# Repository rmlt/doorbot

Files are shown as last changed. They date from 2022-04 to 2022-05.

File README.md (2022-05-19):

# doorbot
Software for our DoorBot

The DoorBot is a device connected to our doorphone that opens the office doors as required.

This software runs on a Raspberry Pi connected to a circuit board that allows it to:
* get input from the doorphone LED and the doorbell button
* simulate pressing a button on the doorphone
* move a servo attached to the door handle
* play sounds

TODO:
* black, isort
* split into modules
* logging instead of printing
* add some photos

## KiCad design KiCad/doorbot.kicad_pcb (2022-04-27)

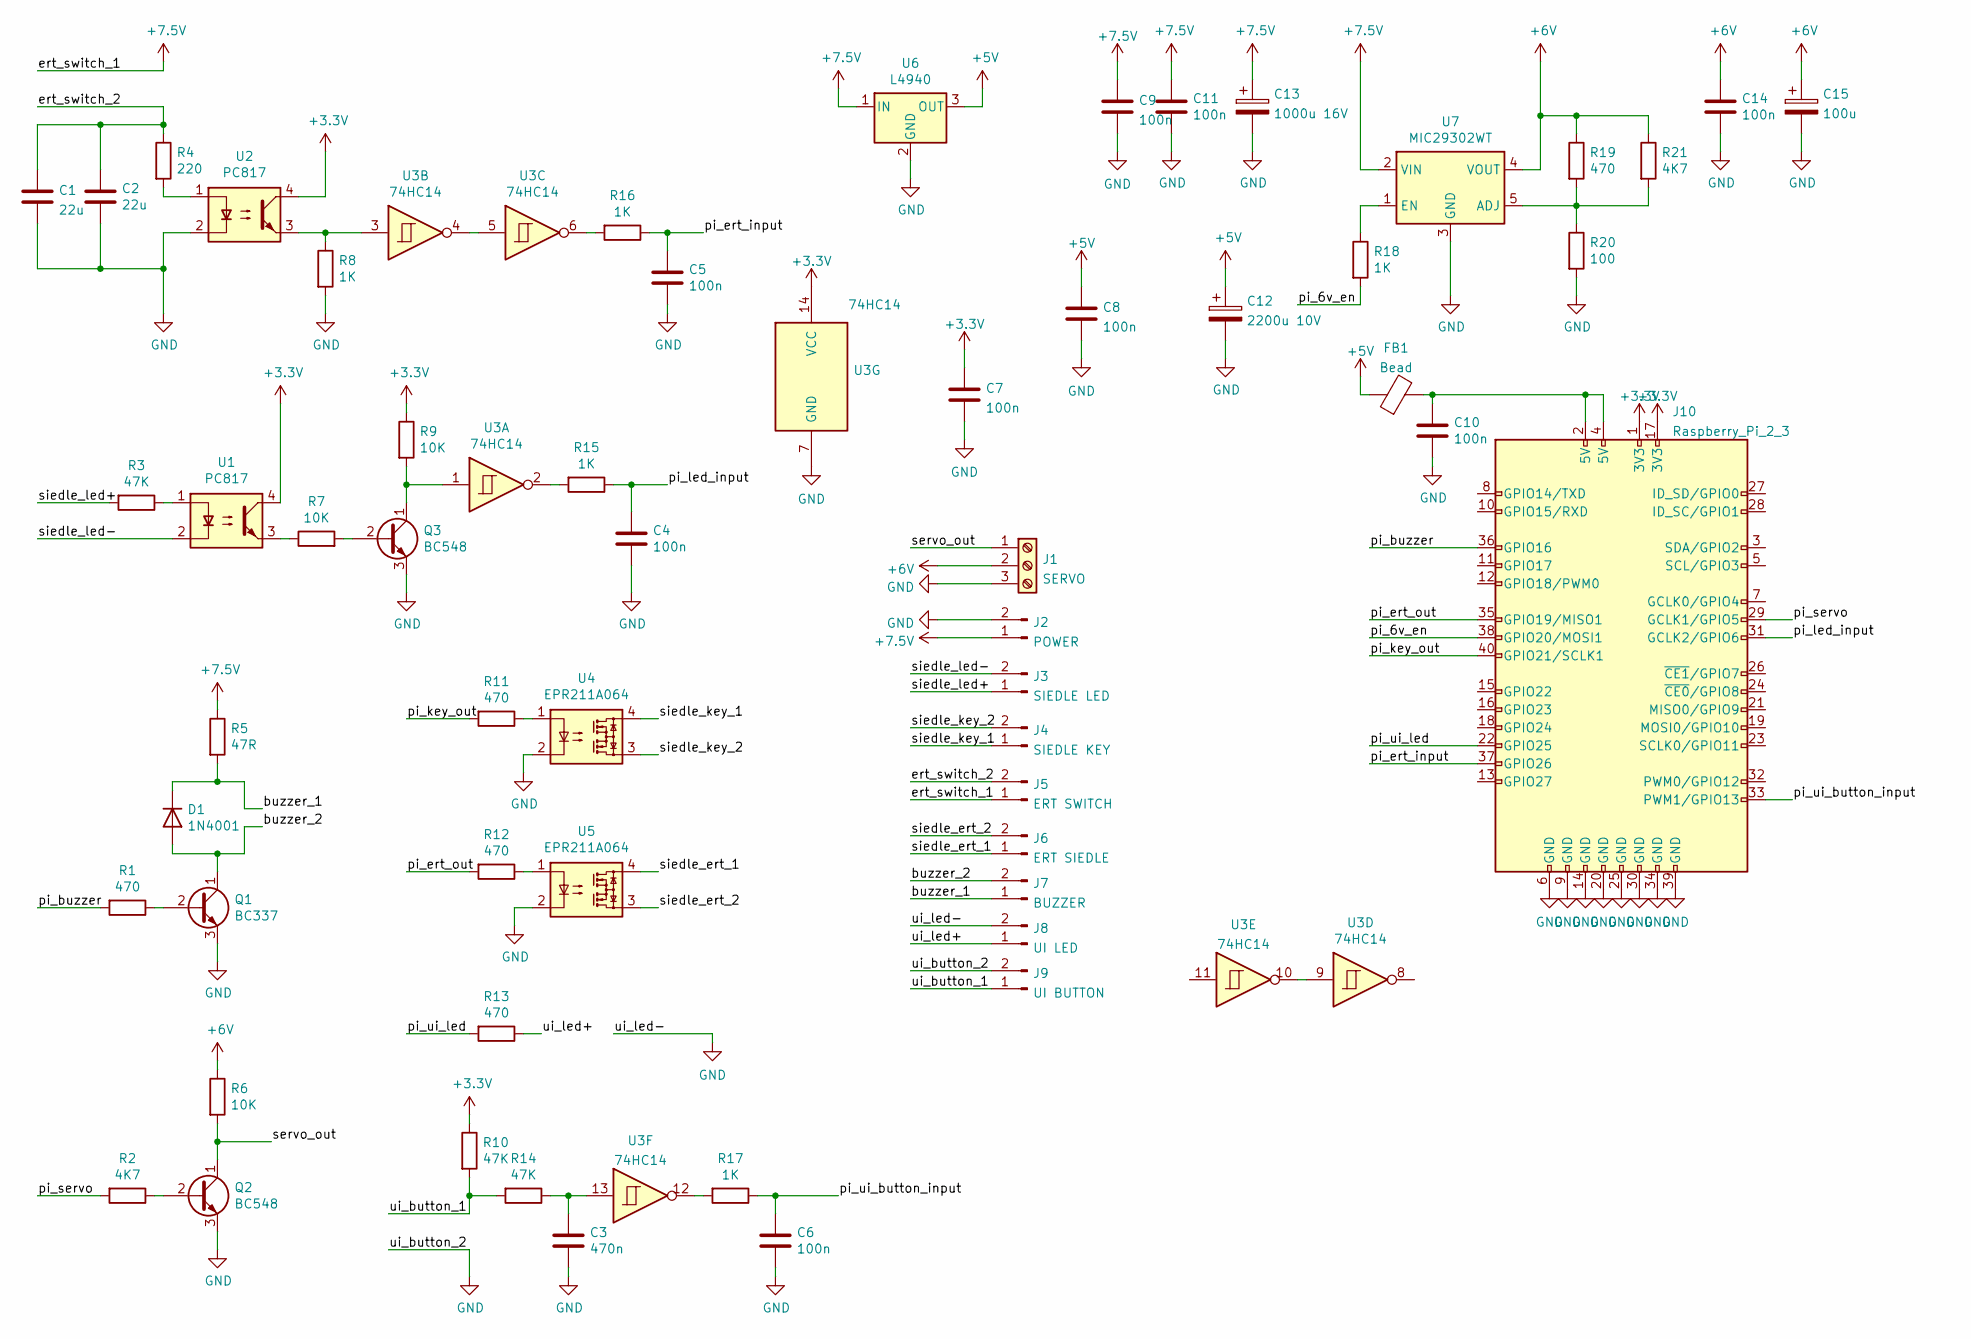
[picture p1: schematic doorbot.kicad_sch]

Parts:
C1, C2: 22u; C_1210_3225Metric
C3: 470n; C_Disc_D5.0mm_W2.5mm_P2.50mm
C4, C5, C6, C8, C9, C10, C11, C14: 100n; C_Disc_D5.0mm_W2.5mm_P2.50mm
C7: 100n; C_Disc_D7.5mm_W5.0mm_P7.50mm
C12: 2200u 10V; CP_Radial_D12.5mm_P5.00mm
C13: 1000u 16V; CP_Radial_D12.5mm_P5.00mm
C15: 100u; CP_Radial_D10.0mm_P2.50mm
D1: 1N4001; D_DO-41_SOD81_P2.54mm_Vertical_AnodeUp
FB1: Bead; R_Axial_DIN0207_L6.3mm_D2.5mm_P10.16mm_Horizontal
J1: SERVO; TerminalBlock_bornier-3_P5.08mm
J2: POWER; PinHeader_1x02_P2.54mm_Vertical
J3: SIEDLE LED; PinHeader_1x02_P2.54mm_Vertical
J4: SIEDLE KEY; PinHeader_1x02_P2.54mm_Vertical
J5: ERT SWITCH; PinHeader_1x02_P2.54mm_Vertical
J6: ERT SIEDLE; PinHeader_1x02_P2.54mm_Vertical
J7: BUZZER; PinHeader_1x02_P2.54mm_Vertical
J8: UI LED; PinHeader_1x02_P2.54mm_Vertical
J9: UI BUTTON; PinHeader_1x02_P2.54mm_Vertical
J10: Raspberry_Pi_2_3; PinSocket_2x20_P2.54mm_Vertical
Q1: BC337; TO-92_Inline_Wide
Q2, Q3: BC548; TO-92_Inline_Wide
R1, R19: 470; R_Axial_DIN0207_L6.3mm_D2.5mm_P2.54mm_Vertical
R2, R21: 4K7; R_Axial_DIN0207_L6.3mm_D2.5mm_P2.54mm_Vertical
R3, R14: 47K; R_Axial_DIN0207_L6.3mm_D2.5mm_P5.08mm_Vertical
R4: 220; R_Axial_DIN0207_L6.3mm_D2.5mm_P2.54mm_Vertical
R5: 47R; R_Axial_DIN0207_L6.3mm_D2.5mm_P5.08mm_Vertical
R6: 10K; R_Axial_DIN0207_L6.3mm_D2.5mm_P2.54mm_Vertical
R7, R9: 10K; R_Axial_DIN0207_L6.3mm_D2.5mm_P10.16mm_Horizontal
R8: 1K; R_Axial_DIN0207_L6.3mm_D2.5mm_P10.16mm_Horizontal
R10: 47K; R_Axial_DIN0309_L9.0mm_D3.2mm_P12.70mm_Horizontal
R11, R13: 470; R_Axial_DIN0207_L6.3mm_D2.5mm_P5.08mm_Vertical
R12: 470; R_Axial_DIN0207_L6.3mm_D2.5mm_P10.16mm_Horizontal
R15: 1K; R_Axial_DIN0309_L9.0mm_D3.2mm_P12.70mm_Horizontal
R16: 1K; R_Axial_DIN0207_L6.3mm_D2.5mm_P15.24mm_Horizontal
R17: 1K; R_Axial_DIN0207_L6.3mm_D2.5mm_P2.54mm_Vertical
R18: 1K; R_Axial_DIN0207_L6.3mm_D2.5mm_P5.08mm_Vertical
R20: 100; R_Axial_DIN0207_L6.3mm_D2.5mm_P5.08mm_Vertical
U1, U2: PC817; DIP-4_W7.62mm
U3: 74HC14; DIP-14_W7.62mm
U4, U5: EPR211A064; DIP-4_W7.62mm
U6: L4940; TO-220-3_Horizontal_TabDown
U7: MIC29302WT; R_Array_SIP5

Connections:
+3V3: C7.1, J10.1 (3V3), J10.17 (3V3), R9.1, R10.1, U1.4, U2.4, U3.14 (VCC)
+5V: C8.1, C12.1, FB1.1, U6.3 (OUT)
+6V: C14.1, C15.1, J1.2, R6.1, R19.1, R21.1, U7.4 (VOUT)
+7.5V: C9.1, C11.1, C13.1, J2.1, J5.1, R5.1, U6.1 (IN), U7.2 (VIN)
/buzzer_1: D1.1 (K), J7.1, R5.2
/buzzer_2: D1.2 (A), J7.2, Q1.1 (C)
/ert_switch_2: C1.1, C2.1, J5.2, R4.1
/pi_6v_en: J10.38 (GPIO20/MOSI1), R18.2
/pi_buzzer: J10.36 (GPIO16), R1.2
/pi_ert_input: C5.1, J10.37 (GPIO26), R16.1
/pi_ert_out: J10.35 (GPIO19/MISO1), R12.2
/pi_key_out: J10.40 (GPIO21/SCLK1), R11.2
/pi_led_input: C4.1, J10.31 (GCLK2/GPIO6), R15.1
/pi_servo: J10.29 (GCLK1/GPIO5), R2.2
/pi_ui_button_input: C6.1, J10.33 (PWM1/GPIO13), R17.1
/pi_ui_led: J10.22 (GPIO25), R13.2
/servo_out: J1.1, Q2.1 (C), R6.2
/siedle_ert_1: J6.1, U5.4
/siedle_ert_2: J6.2, U5.3
/siedle_key_1: J4.1, U4.4
/siedle_key_2: J4.2, U4.3
/siedle_led+: J3.1, R3.2
/siedle_led-: J3.2, U1.2
/ui_button_1: J9.1, R10.2, R14.2
/ui_led+: J8.1, R13.1
GND: C1.2, C2.2, C3.2, C4.2, C5.2, C6.2, C7.2, C8.2, C9.2, C10.2, C11.2, C12.2, C13.2, C14.2, C15.2, J1.3, J2.2, J8.2, J9.2, J10.6 (GND), J10.9 (GND), J10.14 (GND), J10.20 (GND), J10.25 (GND), J10.30 (GND), J10.34 (GND), J10.39 (GND), Q1.3 (E), Q2.3 (E), Q3.3 (E), R8.2, R20.2, U2.2, U3.7 (GND), U4.2, U5.2, U6.2 (GND), U7.3 (GND)
unnamed: C3.1, R14.1, U3.13
unnamed: C10.1, FB1.2, J10.2 (5V), J10.4 (5V)
unnamed: Q1.2 (B), R1.1
unnamed: Q2.2 (B), R2.1
unnamed: Q3.1 (C), R9.2, U3.1
unnamed: Q3.2 (B), R7.2
unnamed: R3.1, U1.1
unnamed: R4.2, U2.1
unnamed: R7.1, U1.3
unnamed: R8.1, U2.3, U3.3
unnamed: R11.1, U4.1
unnamed: R12.1, U5.1
unnamed: R15.2, U3.2
unnamed: R16.2, U3.6
unnamed: R17.2, U3.12
unnamed: R18.1, U7.1 (EN)
unnamed: R19.2, R20.1, R21.2, U7.5 (ADJ)
unnamed: U3.4, U3.5
unnamed: U3.9, U3.10

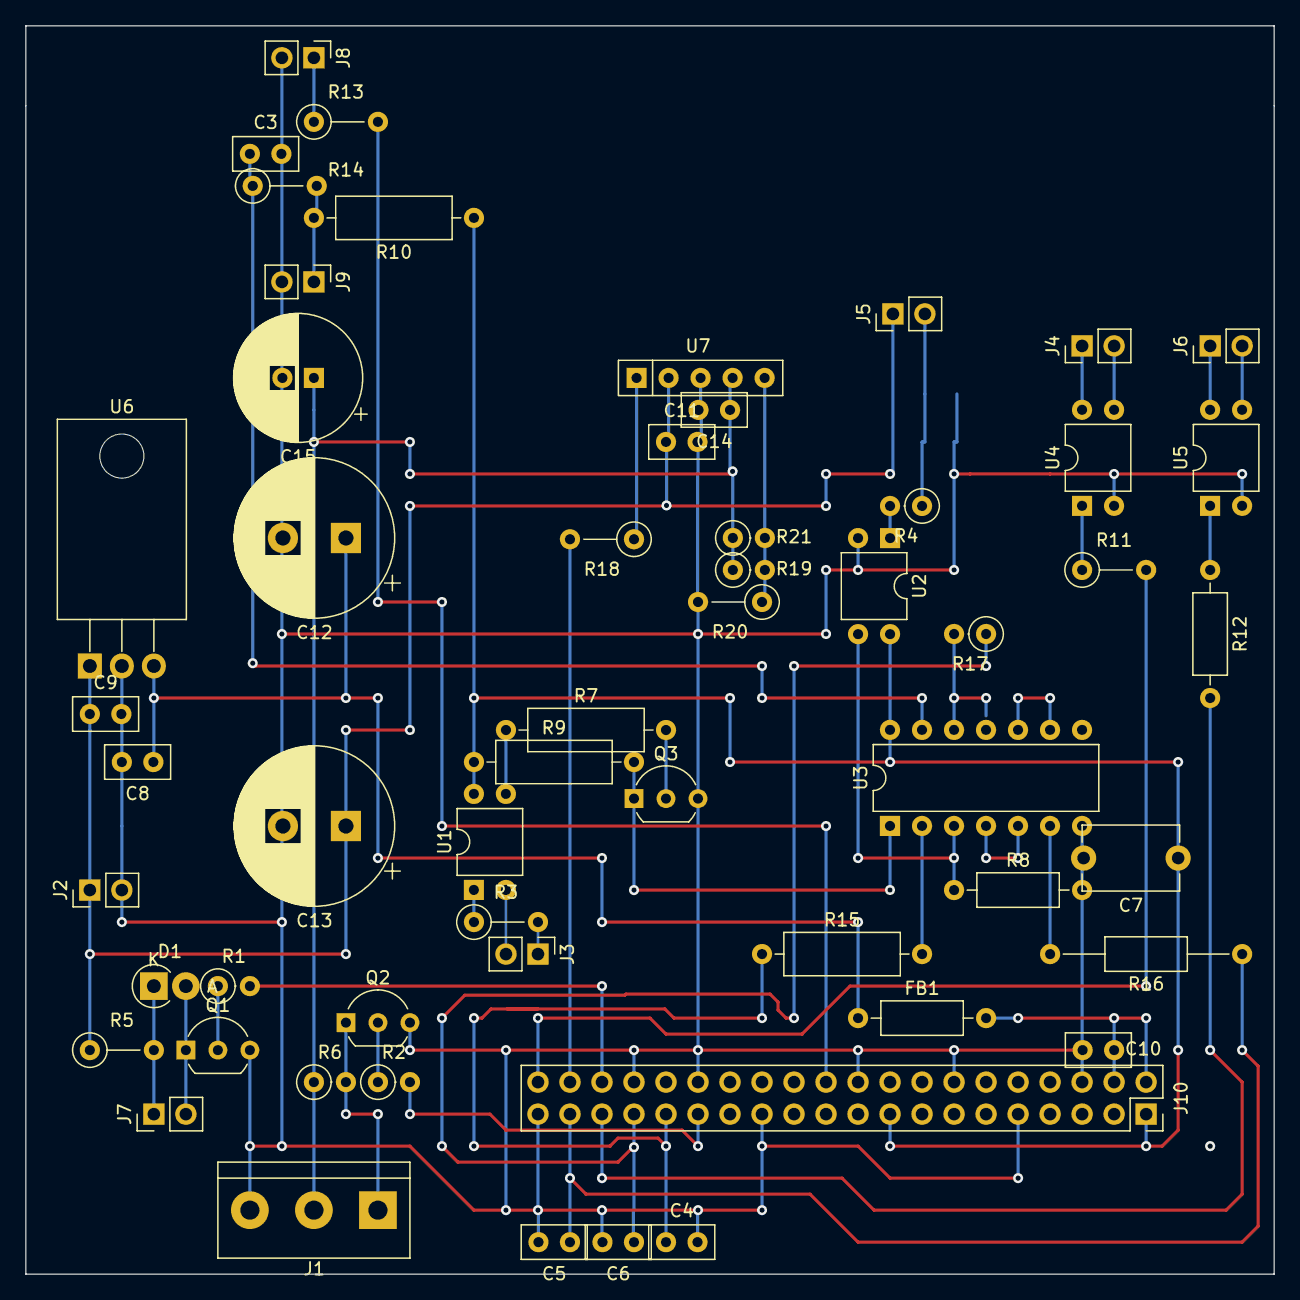
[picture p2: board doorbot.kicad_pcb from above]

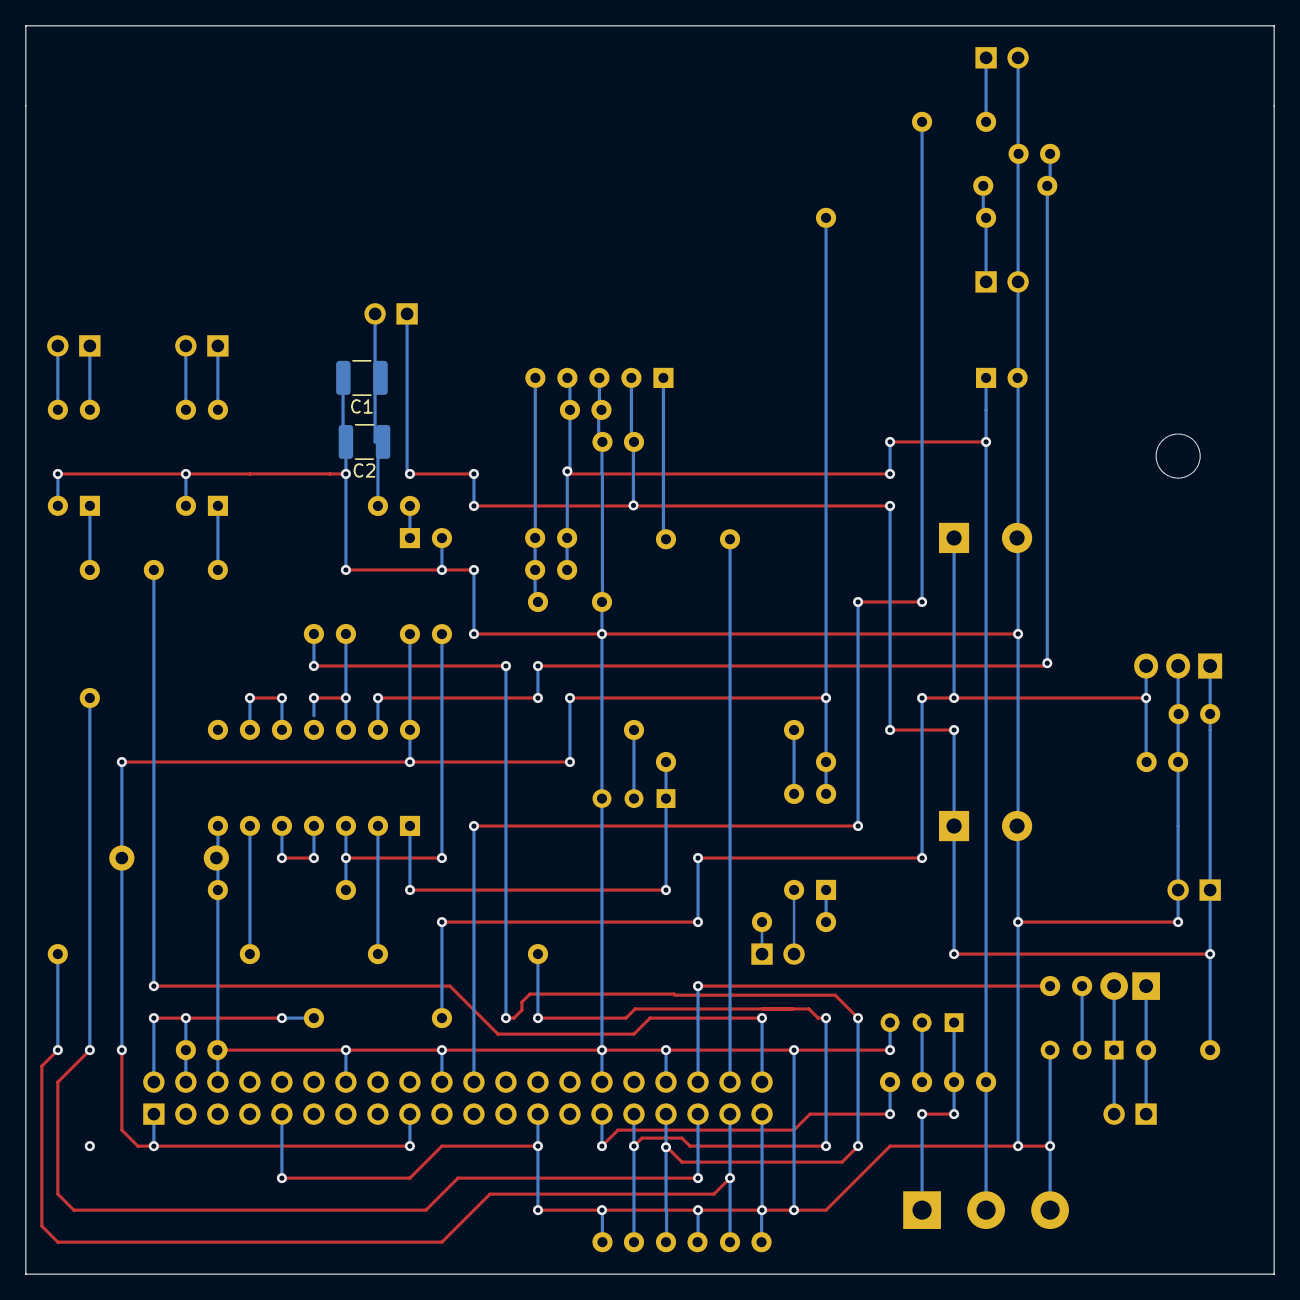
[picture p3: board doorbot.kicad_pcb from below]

Board: 2 copper layers, 99.1 x 99.1 mm, 58 parts (2 on the bottom side), 45 nets.

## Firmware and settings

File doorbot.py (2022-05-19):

#!/usr/bin/env python3

import datetime
import re
import signal
import sys
import threading
from queue import Empty, Queue
from threading import Thread
from time import sleep

import RPi.GPIO as GPIO

from settings import *

# GPIO 0-8 have default pull-ups
# GPIO 9-27 have default pull-downs
INDICATOR_LED_INPUT_GPIO = 6  # siedle
DOORBELL_BUTTON_INPUT_GPIO = 26
UI_BUTTON_INPUT_GPIO = 13

KEY_BUTTON_OUTPUT_GPIO = 21
SERVO_POWER_ENABLE_OUTPUT_GPIO = 20
SERVO_PWM_OUTPUT_GPIO = 5
ERT_CONTACTS_OUTPUT_GPIO = 19
HEARTBEAT_OUTPUT_GPIO = 25  # ui led
BUZZER_OUTPUT_GPIO = 16

MIN_BLINK_PAUSE = 3  # seconds   A blink after at least that time starts a new blinking (phone blinks every 1.2s)
KEY_BUTTON_PRESS_AT_BLINK_COUNT = 4  # =~ 3.6s
KEY_BUTTON_PRESS_AT_BLINK_COUNT_DELAYED = 35  # up to 37
KEY_BUTTON_PRESS_DURATION = 5  # seconds, should be < MIN_BLINK_PAUSE + (KEY_BUTTON_PRESS_AT_BLINK_COUNT - 1) * 1.2

# TODO Make it adaptive
SHORT_PRESS_MAX = datetime.timedelta(seconds=0.8)
LONG_PRESS_MIN = datetime.timedelta(seconds=1.6)

# Shorter for single press to not delay the doorbell after a single press
SINGLE_PRESS_VALID_SEQUENCE_PROCESSING_DELAY = datetime.timedelta(seconds=0.8)
MULTIPLE_PRESS_VALID_SEQUENCE_PROCESSING_DELAY = datetime.timedelta(seconds=2)

INVALID_PRESS_SEQUENCE_CLEAR_TIMEOUT = datetime.timedelta(seconds=5)  # also max recognizable long press duration

# Do not ring the doorbell if button pressed more times than this setting.
# If there are more, the user is most probably trying to enter the code and does not want to ring the bell.
DOOR_OPEN_BUTTON_DOORBELL_SOUND_MAX_PRESSES = 2

ERT_CONTACTS_CONNECT_DURATION = 0.4  # s  Duration of simulated doorbell button press

DOOR_HANDLE_MOVEMENT_DURATION = 2  # s

SERVO_PULSE_FREQUENCY = 50  # Hz
DOOR_HANDLE_DOWN_SERVO_PULSE_LENGTH = 2200  # us
DOOR_HANDLE_UP_SERVO_PULSE_LENGTH = 800  # us

GPIO_EVENT_DOUBLECHECK_DELAY = 0.03  # s
BUSY_WAIT_SLEEP_DURATION = 0.05  # s

HEARTBEAT_PERIOD = 1.5  # s
HEARTBEAT_PERIOD_FAST = 0.25  # s
HEARTBEAT_BLINK = 0.005  # s


assert DOORBELL_MODE in ("chirp", "doorphone")


def format_time(time):
    return time.strftime("%d-%m-%Y %H:%M:%S.%f")


def log(string):
    print(f"{format_time(datetime.datetime.now())}: {string}")


def key_button_loop():
    global threads_should_run
    global should_press_key_button

    while threads_should_run:
        if should_press_key_button:
            should_press_key_button = False
            GPIO.output(KEY_BUTTON_OUTPUT_GPIO, GPIO.HIGH)
            log("key button down")
            sleep(KEY_BUTTON_PRESS_DURATION)
            GPIO.output(KEY_BUTTON_OUTPUT_GPIO, GPIO.LOW)
            # log("key button up")

        sleep(BUSY_WAIT_SLEEP_DURATION)


def doorbell_button_press_processor_loop():
    global doorbell_button_event_queue
    global should_open_door
    global free_office_access

    doorbell_button_events = []

    def is_complete_event_sequence(events):
        """Is it a list of matching downs and ups?"""
        return (
            len(events) % 2 == 0
            and all([e[0] == "down" for e in events[0::2]])
            and all([e[0] == "up" for e in events[1::2]])
        )

    def event_durations(events):
        return [
            event_pair[1][1] - event_pair[0][1]
            for event_pair in zip(doorbell_button_events[0::2], doorbell_button_events[1::2])
        ]

    def events_str(events):
        first = events[0][1].timestamp()
        return " ".join([f"{e[0][0]}{e[1].timestamp() - first:.3f}" for e in events])

    def presses(durations):
        return "".join([d <= SHORT_PRESS_MAX and "." or d >= LONG_PRESS_MIN and "-" or "X" for d in durations])

    def events_match_presses_secret(events, secret):
        if not is_complete_event_sequence(events):
            return False
        durations = event_durations(doorbell_button_events)
        return len(durations) == len(secret) and presses(durations) == secret

    def process_button_event_sequence():
        global should_open_door
        global should_ring_doorbell
        nonlocal doorbell_button_events

        # First event is "up"? We got out of sync, maybe because of a long first press. Remove event.
        if len(doorbell_button_events) > 0 and doorbell_button_events[0][0] == "up":
            doorbell_button_events.pop(0)

        if is_complete_event_sequence(doorbell_button_events) and (
            (
                len(doorbell_button_events) == 2
                and now - doorbell_button_events[-1][1] > SINGLE_PRESS_VALID_SEQUENCE_PROCESSING_DELAY
            )
            or (
                len(doorbell_button_events) > 2
                and now - doorbell_button_events[-1][1] > MULTIPLE_PRESS_VALID_SEQUENCE_PROCESSING_DELAY
            )
        ):
            log(f"processing events: {events_str(doorbell_button_events)}")
            if events_match_presses_secret(doorbell_button_events, DOOR_OPEN_BUTTON_PRESSES_SECRET):
                if access_allowed("office", now):
                    should_open_door = True
            elif events_match_presses_secret(doorbell_button_events, DOOR_OPEN_BUTTON_PRESSES_TOP_SECRET_OVERRIDE):
                should_open_door = True
            else:
                if len(doorbell_button_events) <= 2 * DOOR_OPEN_BUTTON_DOORBELL_SOUND_MAX_PRESSES:
                    should_ring_doorbell = True

            doorbell_button_events = []

        # Special handling of a very long first press - ring before the bell button release.
        # This assumes that the secret sequence starts with a short press.
        if (
            len(doorbell_button_events) == 1
            and doorbell_button_events[0][0] == "down"
            and now - doorbell_button_events[0][1] > SHORT_PRESS_MAX
        ):
            should_ring_doorbell = True
            log(f"long first press: {events_str(doorbell_button_events)}, ringing the bell")
            doorbell_button_events = []

        if (
            not is_complete_event_sequence(doorbell_button_events)
            and now - doorbell_button_events[-1][1] > INVALID_PRESS_SEQUENCE_CLEAR_TIMEOUT
        ):
            log(f"resetting invalid events: {events_str(doorbell_button_events)}")
            # Either spurious GPIO event or too much switch bounce. Do nothing, the person can try again or knock.
            doorbell_button_events = []

    while threads_should_run:
        try:
            item = doorbell_button_event_queue.get(block=False)
            doorbell_button_events.append(item)
            doorbell_button_event_queue.task_done()
        except Empty:
            pass

        now = datetime.datetime.now()

        if len(doorbell_button_events) > 0:
            if free_office_access_enabled() and any([e[0] == "down" for e in doorbell_button_events]):
                should_open_door = True
                doorbell_button_events = []
            else:
                process_button_event_sequence()

        sleep(BUSY_WAIT_SLEEP_DURATION)


def free_office_access_enabled():
    global free_office_access
    global last_ui_button_pressed_at

    return free_office_access and (
        datetime.datetime.now() - last_ui_button_pressed_at <= datetime.timedelta(seconds=FREE_OFFICE_ACCESS_DURATION)
    )


# Enable office access for 1 hour after button press
def ui_button_press_processor_loop():
    global ui_button_event_queue
    global free_office_access
    global last_ui_button_pressed_at

    ui_button_events = []

    while threads_should_run:
        try:
            item = ui_button_event_queue.get(block=False)
            ui_button_events.append(item)
            ui_button_event_queue.task_done()
        except Empty:
            pass

        for e in ui_button_events:
            if e[0] == "down":  # button pressed since last check?
                last_ui_button_pressed_at = e[1]
                buzzer_queue.put(CHIRPS["beep"])
                if free_office_access_enabled():
                    free_office_access = False
                else:
                    free_office_access = True

                break

        ui_button_events = []

        sleep(BUSY_WAIT_SLEEP_DURATION)


# The servo PWM signal buffer in our hardware inverts the signal, this is taken into account
def door_servo_loop():
    global threads_should_run
    global should_open_door

    pwm = GPIO.PWM(SERVO_PWM_OUTPUT_GPIO, SERVO_PULSE_FREQUENCY)
    pwm.start(100)  # 100% high, inverts to 100% low

    def set_servo_pulse_length(pulse_length_us):
        pwm_percentage = 100 * (1 - (pulse_length_us / 1000000) * SERVO_PULSE_FREQUENCY)
        pwm.ChangeDutyCycle(pwm_percentage)

    while threads_should_run:
        if should_open_door:
            GPIO.output(SERVO_POWER_ENABLE_OUTPUT_GPIO, GPIO.HIGH)
            set_servo_pulse_length(DOOR_HANDLE_DOWN_SERVO_PULSE_LENGTH)
            log("handle down")
            sleep(DOOR_HANDLE_MOVEMENT_DURATION)  # handle moving down
            set_servo_pulse_length(DOOR_HANDLE_UP_SERVO_PULSE_LENGTH)
            # log("handle up")
            sleep(DOOR_HANDLE_MOVEMENT_DURATION)  # handle moving up
            set_servo_pulse_length(0)
            GPIO.output(SERVO_POWER_ENABLE_OUTPUT_GPIO, GPIO.LOW)
            should_open_door = False

        sleep(BUSY_WAIT_SLEEP_DURATION)


def doorbell_ring_loop():
    global threads_should_run
    global should_ring_doorbell

    while threads_should_run:
        if should_ring_doorbell:
            should_ring_doorbell = False

            if DOORBELL_MODE == "chirp":
                buzzer_queue.put(CHIRPS["doorbell"])
            elif DOORBELL_MODE == "doorphone":
                GPIO.output(ERT_CONTACTS_OUTPUT_GPIO, GPIO.HIGH)
                log("ert contacts connected")
                sleep(ERT_CONTACTS_CONNECT_DURATION)
                GPIO.output(ERT_CONTACTS_OUTPUT_GPIO, GPIO.LOW)
                # log("ert contacts disconnected")

        sleep(BUSY_WAIT_SLEEP_DURATION)


def buzzer_loop():
    global threads_should_run
    global buzzer_queue

    while threads_should_run:
        try:
            chirp = buzzer_queue.get(block=False)

            # Play the chirp - an iterable containing tuples (frequency [Hz], duration [s])
            pwm = GPIO.PWM(BUZZER_OUTPUT_GPIO, chirp[0][0])
            pwm.start(0)
            pwm.ChangeDutyCycle(50)
            for freq, duration in chirp:
                pwm.ChangeFrequency(freq)
                sleep(duration)
            pwm.stop(0)
            GPIO.output(BUZZER_OUTPUT_GPIO, GPIO.LOW)

            buzzer_queue.task_done()
        except Empty:
            pass

        sleep(BUSY_WAIT_SLEEP_DURATION)


def heartbeat_loop():
    global threads_should_run

    while threads_should_run:
        # blink faster if free office access enabled
        period = HEARTBEAT_PERIOD_FAST if free_office_access_enabled() else HEARTBEAT_PERIOD
        assert period > HEARTBEAT_BLINK

        GPIO.output(HEARTBEAT_OUTPUT_GPIO, GPIO.HIGH)
        sleep(HEARTBEAT_BLINK)
        GPIO.output(HEARTBEAT_OUTPUT_GPIO, GPIO.LOW)
        sleep(period - HEARTBEAT_BLINK)


def access_allowed(kind, time):
    def dot(a, b):
        return a[0] * b[0] + a[1] * b[1]

    weekdays, start_time, end_time = DOOR_OPENING_TIME_RANGE[kind]

    assert weekdays in ("mon-fri", "sat-sun")  # TODO more flexibility
    # Monday is 0 and Sunday is 6
    if not ((weekdays == "mon-fri" and time.weekday() <= 4) or (weekdays == "sat-sun" and time.weekday() >= 5)):
        return False

    min_elapsed_minutes = dot([int(x) for x in start_time.split(":")], (60, 1))
    max_elapsed_minutes = dot([int(x) for x in end_time.split(":")], (60, 1))
    elapsed_day_minutes = time.hour * 60 + time.minute

    return min_elapsed_minutes <= elapsed_day_minutes <= max_elapsed_minutes


def led_on_handler(channel):
    global threads_should_run
    global buzzer_queue
    global should_press_key_button
    global last_led_on_time
    global blink_count

    if not threads_should_run:
        return

    now = datetime.datetime.now()

    sleep(GPIO_EVENT_DOUBLECHECK_DELAY)
    if GPIO.input(INDICATOR_LED_INPUT_GPIO) != GPIO.HIGH:
        return  # spurious input spike

    if last_led_on_time is None or (now - last_led_on_time).seconds >= MIN_BLINK_PAUSE:
        last_led_on_time = now
        blink_count = 1
        log(f"new blinking sequence @ {now}")
    else:
        last_led_on_time = now
        blink_count += 1
        # log(f"blink #{blink_count}")

    if (blink_count == KEY_BUTTON_PRESS_AT_BLINK_COUNT and access_allowed("downstairs_immediate", now)) or (
        blink_count == KEY_BUTTON_PRESS_AT_BLINK_COUNT_DELAYED and access_allowed("downstairs_delayed", now)
    ):
        should_press_key_button = True
        buzzer_queue.put(CHIRPS["key_button_press_confirmation"])


def doorbell_button_handler(channel):
    global doorbell_button_event_queue
    global threads_should_run

    if not threads_should_run:
        return

    now = datetime.datetime.now()

    if GPIO.input(DOORBELL_BUTTON_INPUT_GPIO) == GPIO.HIGH:
        sleep(GPIO_EVENT_DOUBLECHECK_DELAY)
        if GPIO.input(DOORBELL_BUTTON_INPUT_GPIO) == GPIO.HIGH:
            doorbell_button_event_queue.put(("down", now))

    if GPIO.input(DOORBELL_BUTTON_INPUT_GPIO) == GPIO.LOW:
        sleep(GPIO_EVENT_DOUBLECHECK_DELAY)
        if GPIO.input(DOORBELL_BUTTON_INPUT_GPIO) == GPIO.LOW:
            doorbell_button_event_queue.put(("up", now))


def ui_button_handler(channel):
    global ui_button_event_queue
    global threads_should_run

    if not threads_should_run:
        return

    now = datetime.datetime.now()

    if GPIO.input(UI_BUTTON_INPUT_GPIO) == GPIO.HIGH:
        sleep(GPIO_EVENT_DOUBLECHECK_DELAY)
        if GPIO.input(UI_BUTTON_INPUT_GPIO) == GPIO.HIGH:
            ui_button_event_queue.put(("down", now))

    if GPIO.input(UI_BUTTON_INPUT_GPIO) == GPIO.LOW:
        sleep(GPIO_EVENT_DOUBLECHECK_DELAY)
        if GPIO.input(UI_BUTTON_INPUT_GPIO) == GPIO.LOW:
            ui_button_event_queue.put(("up", now))


def signal_handler(sig, frame):
    global doorbell_button_event_queue
    global ui_button_event_queue
    global buzzer_queue
    global threads_should_run
    global threads

    print("Cleaning up...")

    threads_should_run = False
    for thread in threads:
        thread.join()

    doorbell_button_event_queue.join()
    ui_button_event_queue.join()
    buzzer_queue.join()

    GPIO.cleanup()
    sys.exit(0)


if __name__ == "__main__":
    global doorbell_button_event_queue
    global ui_button_event_queue
    global buzzer_queue
    global threads
    global threads_should_run

    global last_led_on_time
    global blink_count
    global should_press_key_button

    global should_open_door
    global should_ring_doorbell
    global free_office_access

    # Communication doorbell_button_handler => doorbell_button_press_processor_loop
    # stores tuples (press start time, press end time)
    doorbell_button_event_queue = Queue()

    # Presses of the UI button, stores tuples (press start time, press end time)
    ui_button_event_queue = Queue()

    # chirps to be played
    buzzer_queue = Queue()

    threads = []
    threads_should_run = True

    last_led_on_time = None
    blink_count = 0
    should_press_key_button = False

    should_open_door = False
    should_ring_doorbell = False
    free_office_access = False  # if True, office door is opened immediately when doorbell button (ERT) is pressed

    assert (
        DOOR_OPEN_BUTTON_PRESSES_SECRET[0] == "." and DOOR_OPEN_BUTTON_PRESSES_TOP_SECRET_OVERRIDE[0] == "."
    ), "Door open secret must start with a short press (.)"

    GPIO.setwarnings(False)
    GPIO.setmode(GPIO.BCM)

    GPIO.setup(INDICATOR_LED_INPUT_GPIO, GPIO.IN, pull_up_down=GPIO.PUD_UP)
    GPIO.setup(DOORBELL_BUTTON_INPUT_GPIO, GPIO.IN, pull_up_down=GPIO.PUD_DOWN)
    GPIO.setup(UI_BUTTON_INPUT_GPIO, GPIO.IN, pull_up_down=GPIO.PUD_DOWN)

    GPIO.setup(KEY_BUTTON_OUTPUT_GPIO, GPIO.OUT, initial=GPIO.LOW)
    GPIO.setup(SERVO_POWER_ENABLE_OUTPUT_GPIO, GPIO.OUT, initial=GPIO.LOW)
    GPIO.setup(SERVO_PWM_OUTPUT_GPIO, GPIO.OUT, initial=GPIO.HIGH)
    GPIO.setup(ERT_CONTACTS_OUTPUT_GPIO, GPIO.OUT, initial=GPIO.LOW)
    GPIO.setup(HEARTBEAT_OUTPUT_GPIO, GPIO.OUT, initial=GPIO.LOW)
    GPIO.setup(BUZZER_OUTPUT_GPIO, GPIO.OUT, initial=GPIO.LOW)

    for loop in (
        key_button_loop,
        doorbell_button_press_processor_loop,
        ui_button_press_processor_loop,
        door_servo_loop,
        doorbell_ring_loop,
        buzzer_loop,
        heartbeat_loop,
    ):
        threads.append(Thread(target=loop))

    for thread in threads:
        thread.start()

    GPIO.add_event_detect(INDICATOR_LED_INPUT_GPIO, GPIO.RISING, callback=led_on_handler)

    GPIO.add_event_detect(DOORBELL_BUTTON_INPUT_GPIO, GPIO.BOTH, callback=doorbell_button_handler, bouncetime=50)

    GPIO.add_event_detect(UI_BUTTON_INPUT_GPIO, GPIO.BOTH, callback=ui_button_handler, bouncetime=50)

    signal.signal(signal.SIGINT, signal_handler)
    signal.pause()

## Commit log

2020-10-02 Implement opening the door when the button is pressed (for tests only)
2020-10-02 Implement doorbell button press detection for door opening
2020-10-02 Add missing initial values for output GPIO pins
    [doorbot.py]
2021-12-06 Play chirps for doorbell and key button press confirmation
2022-01-24 Add circuit diagram
    [doorbot.sch]
2022-02-14 Migrate schematic to KiCad 6, add connectors and Raspberry Pi
    [doorbot.kicad_sch]
2022-02-14 Add netlist and initial PCB
    [doorbot.kicad_pcb]
2022-02-21 Route the stripboard PCB
    [doorbot.kicad_pcb, doorbot.kicad_sch]
2022-02-21 Add UI button GPIO assignment
2022-04-27 Add the final PCB version
    [doorbot.kicad_pcb, doorbot.kicad_sch]
2022-04-27 Add support for UI button
